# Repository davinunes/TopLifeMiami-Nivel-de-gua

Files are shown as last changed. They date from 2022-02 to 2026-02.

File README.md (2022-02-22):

# TopLifeMiami-Nivel-de-gua
Projeto para monitoramento de nível de água do Miami Beach

## Conceito

Utilizar um Sensor ultrassonico para medir o que falta de água no tanque, e calcular o que tem de água.
Então, exibir a medida atual na tela e a cada período de tempo, publicar os dados na internet.

> Esse projeto requer sinal de WiFi proximo ao microcontrolador.

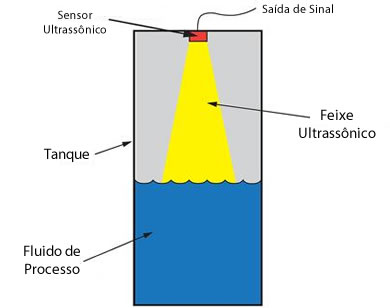
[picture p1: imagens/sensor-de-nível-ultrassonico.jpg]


Foram explorados três métodos de publicação na Internet:

- Plataforma **Adafruit.io**, um broquer MQTT popular em projetos de automação [link](https://io.adafruit.com/ilunne/dashboards/agua?kiosk=true)
- Um site particular, representando um sistema hospedado na nuvem [link](http://davinunes.eti.br/Agua/)
- API do telegram, enviando mensagens periódicas, representando um sistema de alerta

## Material RECOMENDADO

> Nota: Alguns materiais, como cano e cabo, podem ser adquiridos por metro, diminuindo o custo. Ou mesmo utilizar resto que já exista em estoque.

### Itens Essenciais

#### Sensor de Ultrassom
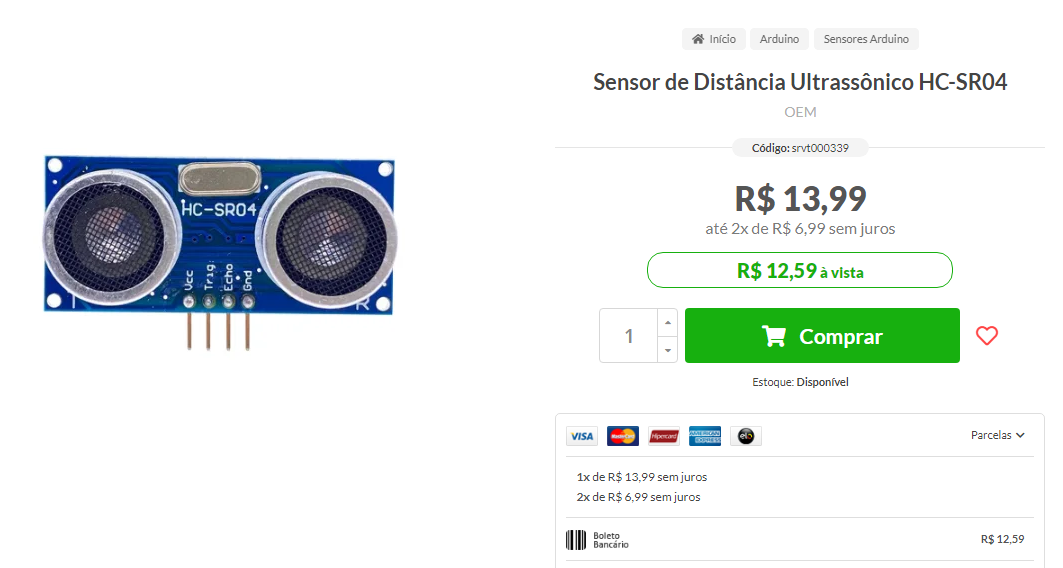
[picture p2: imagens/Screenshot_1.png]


#### Microcontrolador com WiFi
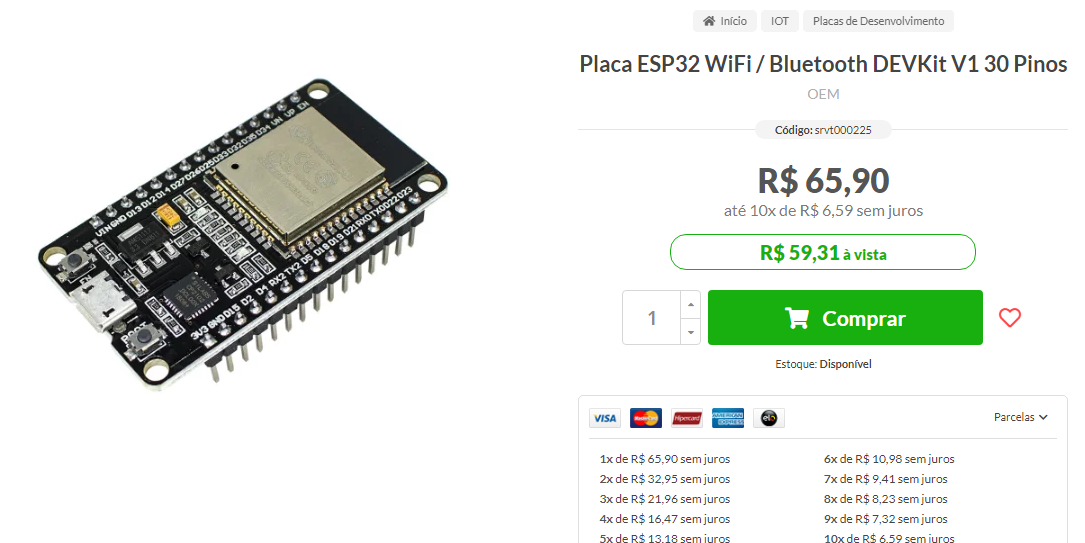
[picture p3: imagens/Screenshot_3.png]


#### Carregador de Celular com cabo microusb
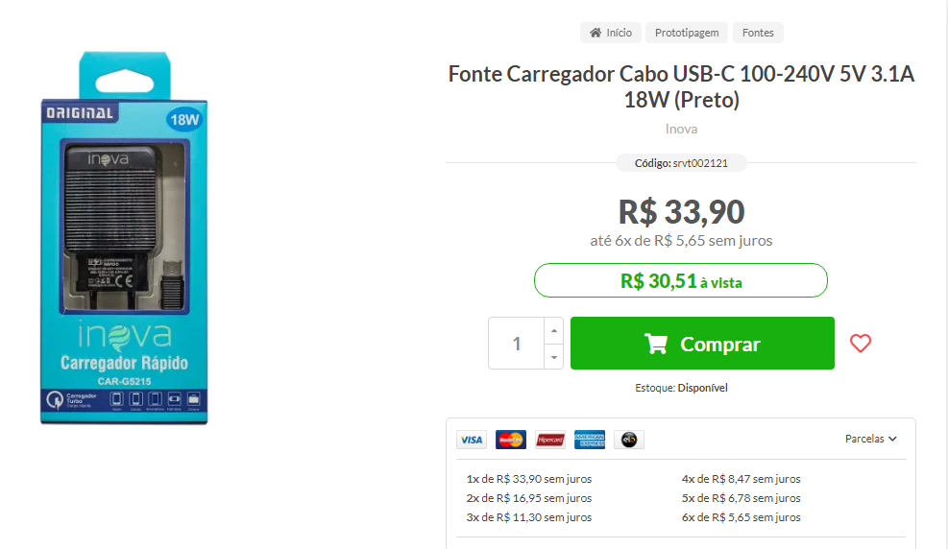
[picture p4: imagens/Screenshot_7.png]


### Itens opcionais e/ou acabamento do projeto

#### Tela de OLED
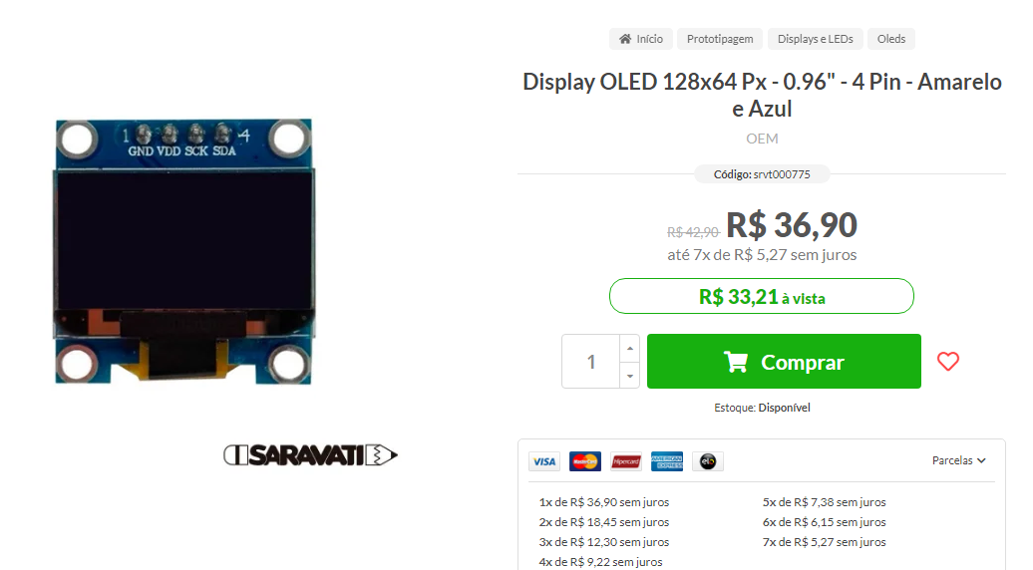
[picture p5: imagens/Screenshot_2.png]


#### Cabo para conexão com a Tela e adaptação do sensor
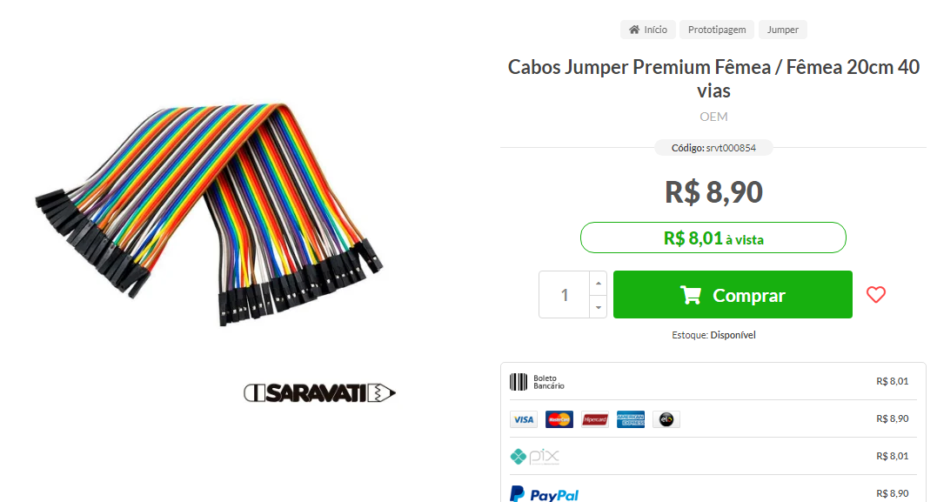
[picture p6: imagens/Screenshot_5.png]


#### Tubo para isolamento de emendas

> Ou use fita isolante

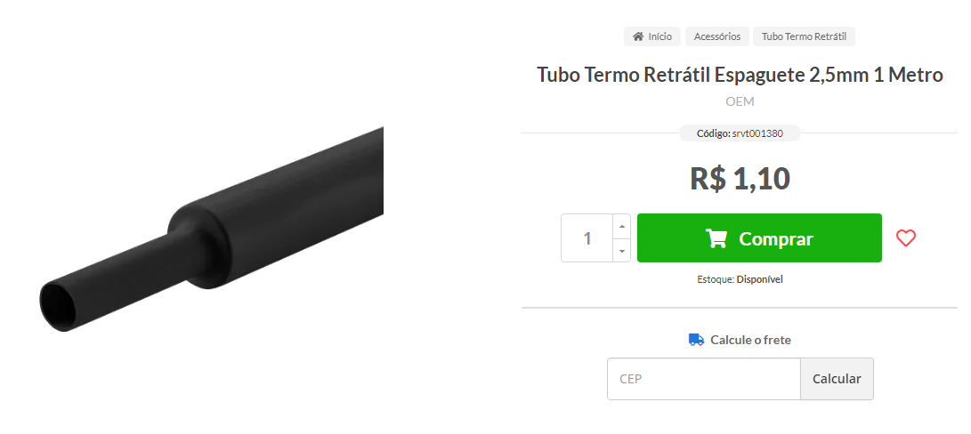
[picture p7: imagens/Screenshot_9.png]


#### Cabo para conextar o sensor da caixa ao controlador
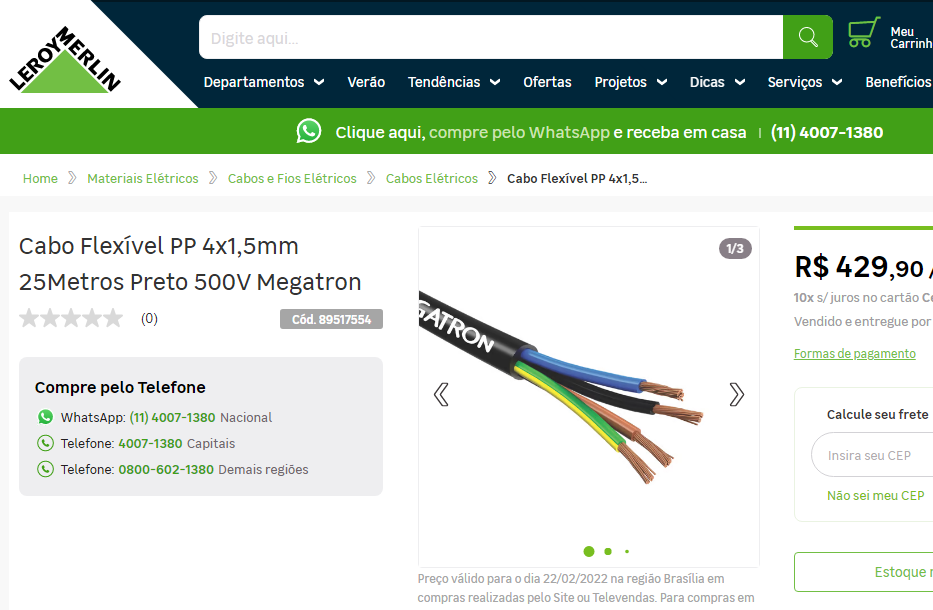
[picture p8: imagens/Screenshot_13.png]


#### Pode ser utilizado cabo de rede, em vez de cobo anterior
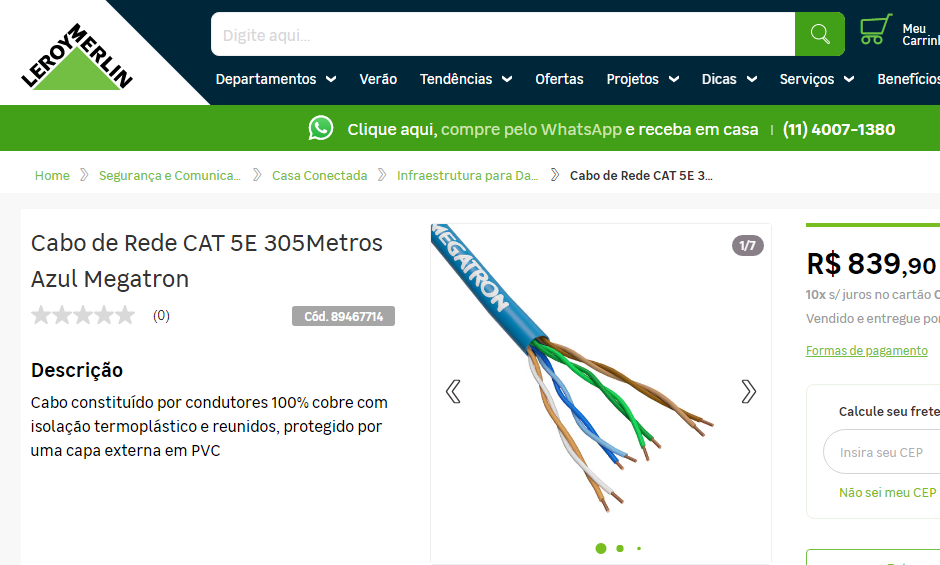
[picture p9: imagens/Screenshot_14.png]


#### CAP 50mm Esgoto, com anel de vedação
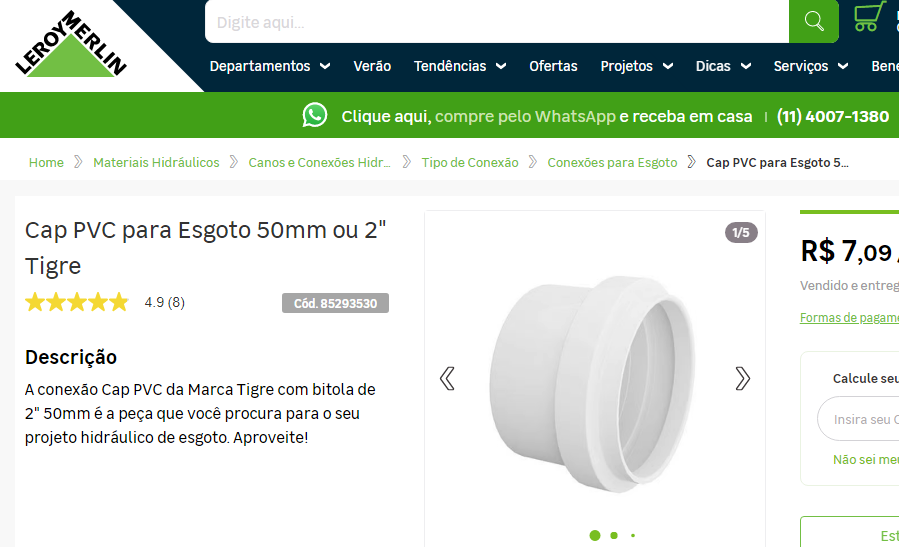
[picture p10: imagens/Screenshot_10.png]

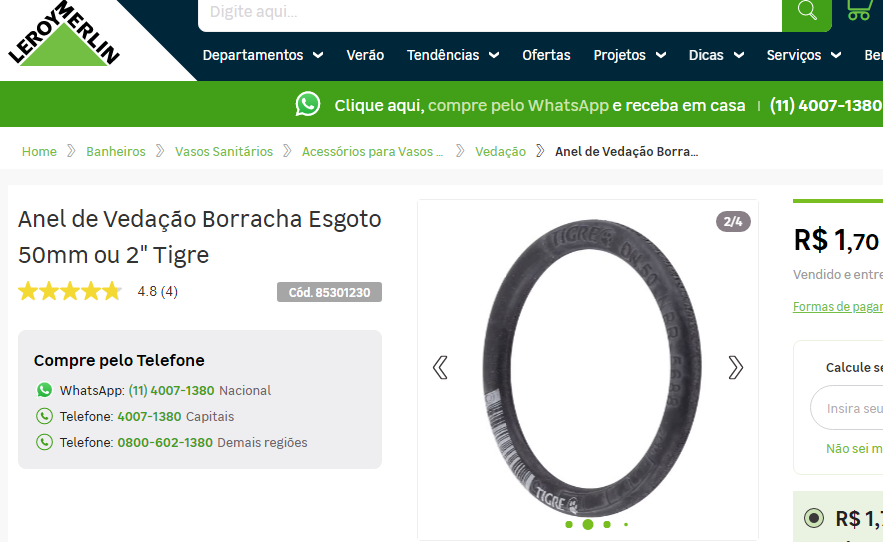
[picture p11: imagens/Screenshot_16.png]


> Nota: Se for utilizar o sensor impermeável, substituir esses dois itens e a redução de 50/25 por um cap de 25.

#### Redução 50/25mm água
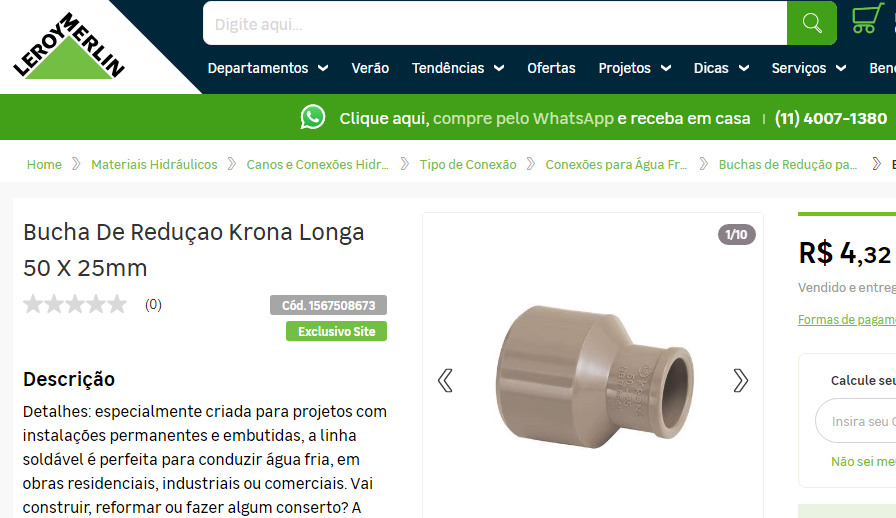
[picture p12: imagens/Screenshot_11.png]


#### Pedaço de cano de 25mm
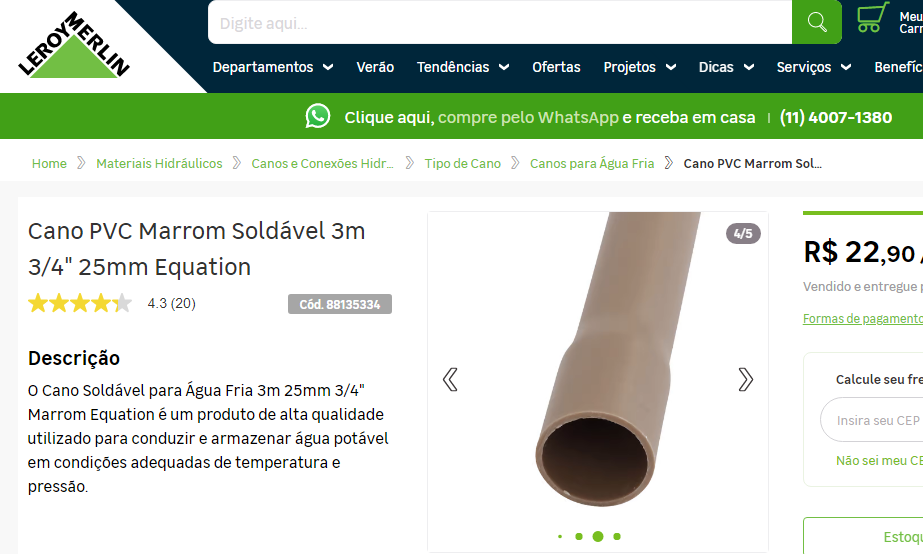
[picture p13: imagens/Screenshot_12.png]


#### Caixa de sobrepor com tampa cega
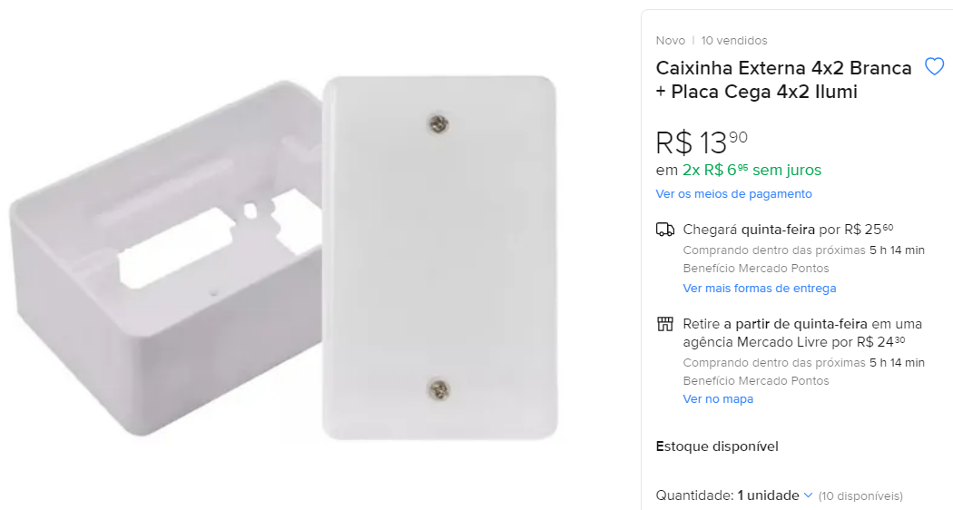
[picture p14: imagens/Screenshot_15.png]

Para instalar o LCD e acomodar o ESP32

## Execução do projeto

> O código fonte do programa está neste projeto.

- Copie o código do programa para o seu computador
- Instale a IDE Arduino, e instale as Bibliotecas Adafruit MQTT, Ultrassoinic, SSD1306
- Crie um bot no Telegram, crie um char e anote o token e o id do Chat
- Crie uma conta na Adafruit e anote o token
- Crie um site que tenha uma página que recebe dois parametros, Sendo ID do Sensor e Valor

#### A montagem das peças:

O esquema de conexão dos fios segue:
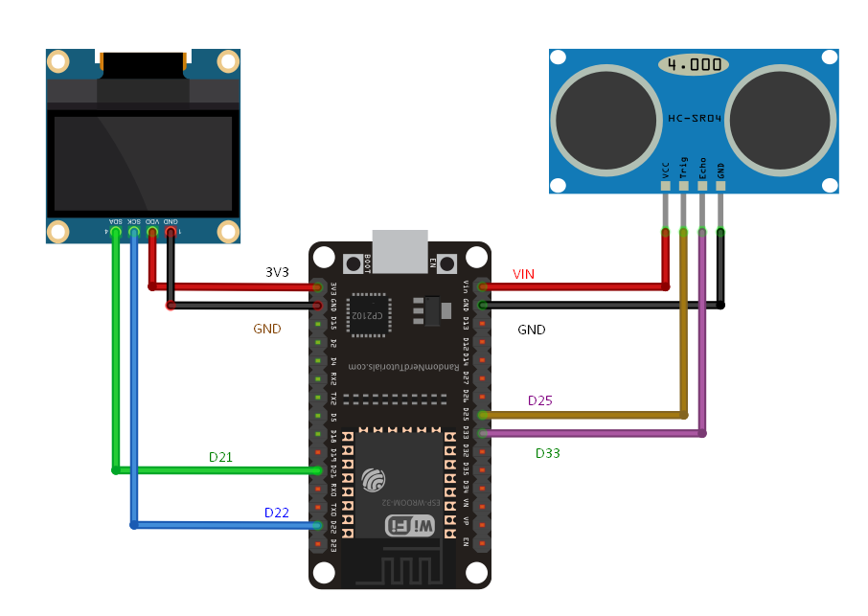
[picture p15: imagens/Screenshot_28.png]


Fure o CAP de modo que o sensor encaixe bem justo

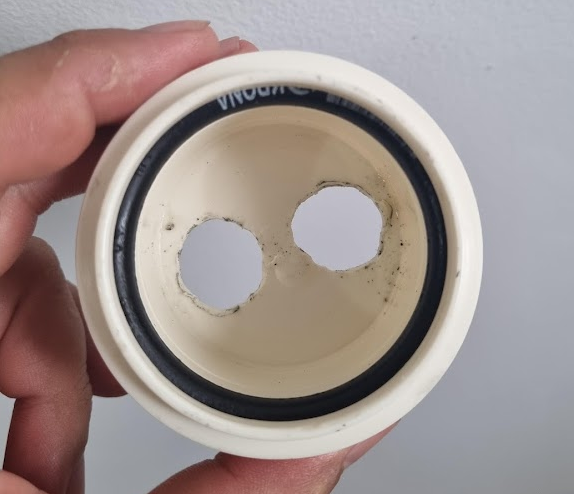
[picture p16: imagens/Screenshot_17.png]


Utilize algum material para servir de apoio ao sensor. Eu utilizei um pedaço de isopor

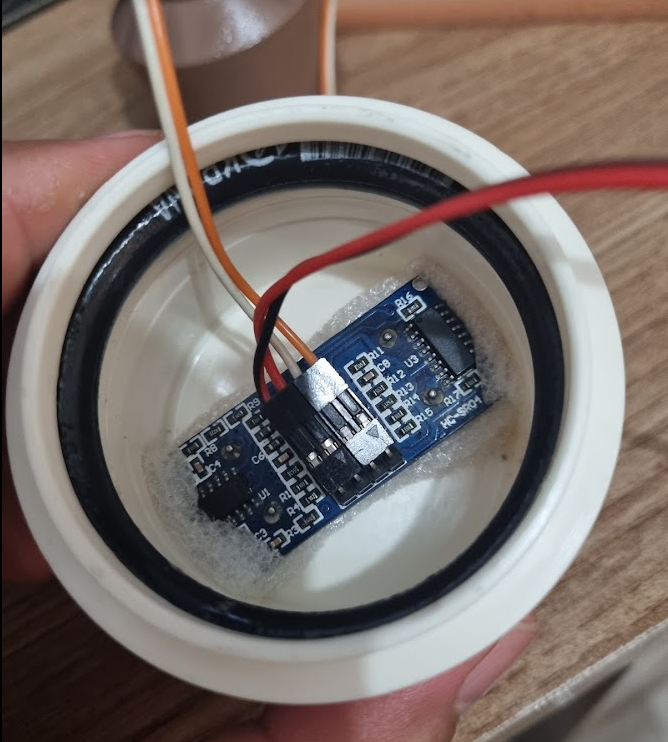
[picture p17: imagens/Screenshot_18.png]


Ajuste a altura pra sona não ficar muito pra fora

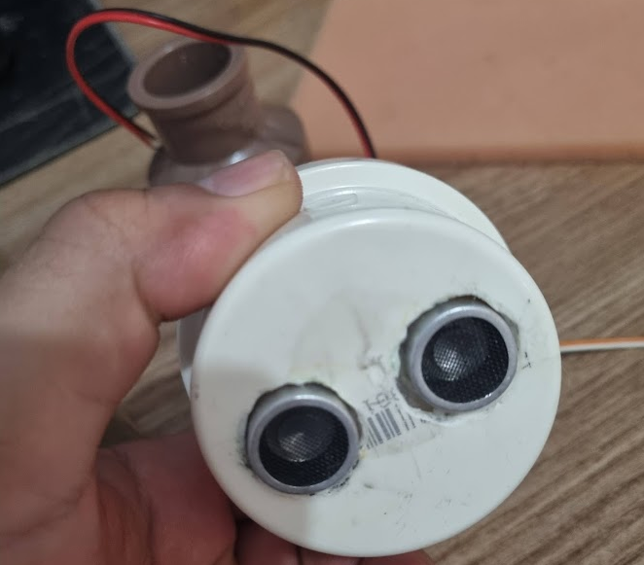
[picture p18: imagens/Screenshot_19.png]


Faça as emendas necessárias e ANOTE a sequencia correta dos fios, seguindo o codigo do projeto

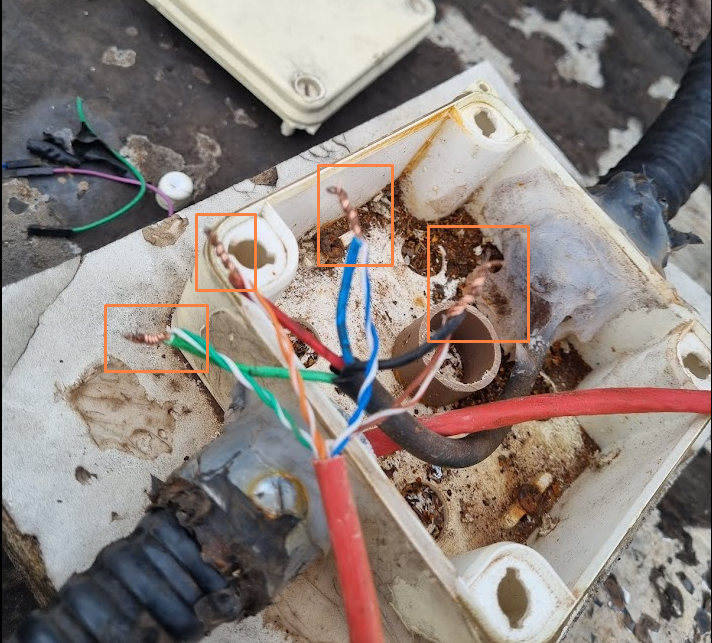
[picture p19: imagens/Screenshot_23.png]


Encaise o cap, a redução e um pedaço de cano, com o já conectado ao sensor e fixe na caixa. A Sonda não deve encostar na água

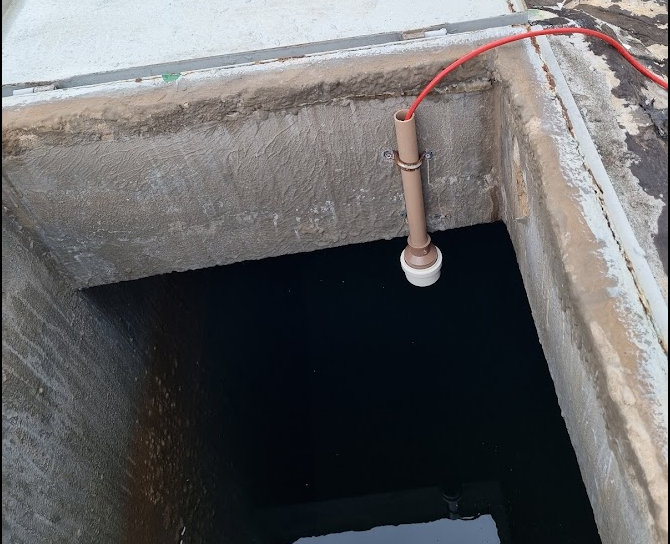
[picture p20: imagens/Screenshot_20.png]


Com uma trena, meça quantos centimetros tem entre a sonda e o nivel maximo da água. Essa informação deve ser inserida no programa antes de gravar

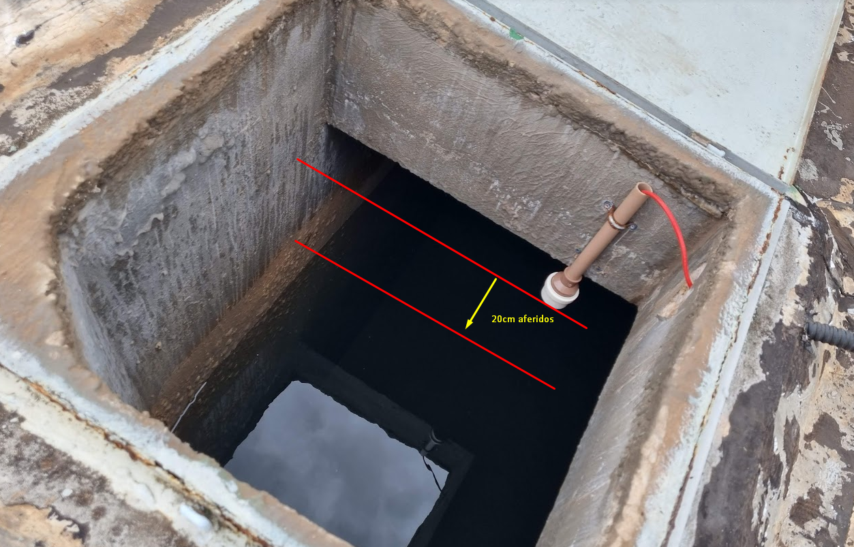
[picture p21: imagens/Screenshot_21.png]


Faça os acabamentos necessários. Esta etapa pode variar de caso a caso

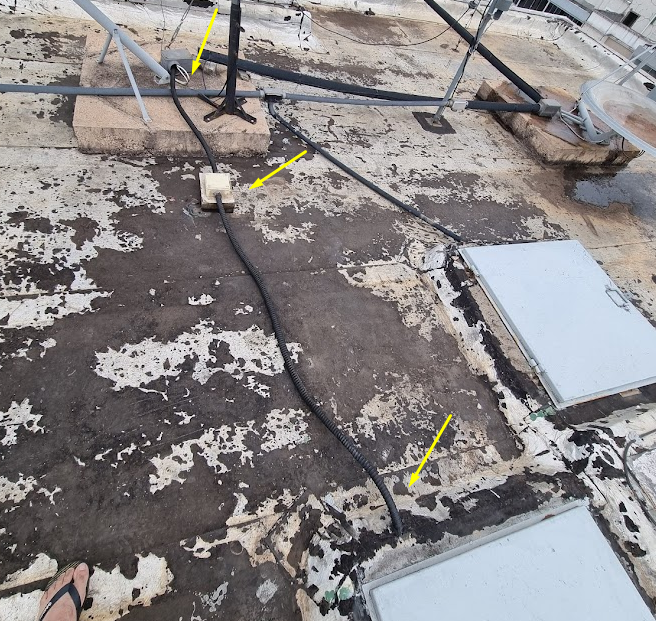
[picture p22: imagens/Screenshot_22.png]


Na casa de máquinas, ou onde for ficar o microcontrolador, faça as conexões conforme o projeto

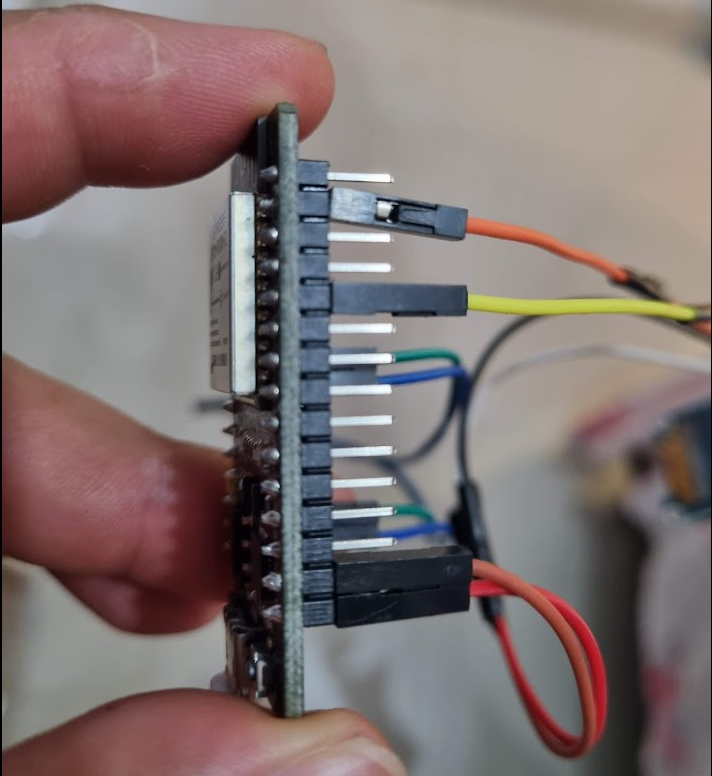
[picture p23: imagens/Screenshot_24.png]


Imagem do armário na casa de máquinas

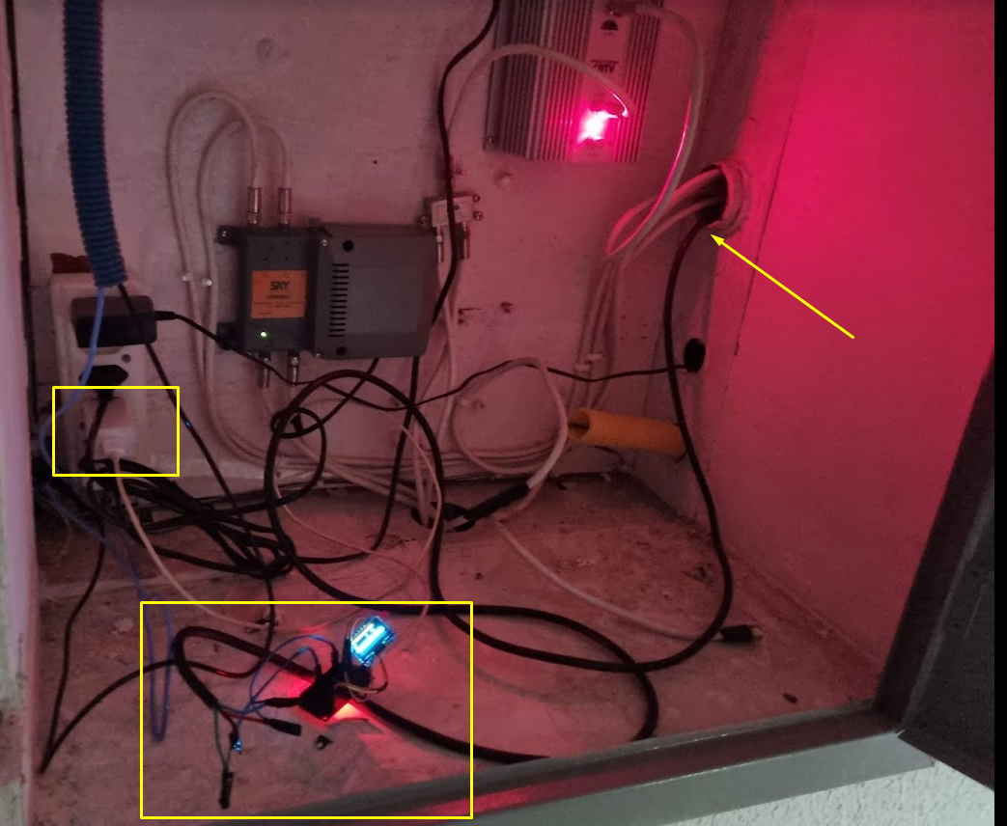
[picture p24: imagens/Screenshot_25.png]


> É verdade, ficou bem feio mas vamos logo mais acomodar em uma caixa de sobrepor e prender a tela na tampa cega.

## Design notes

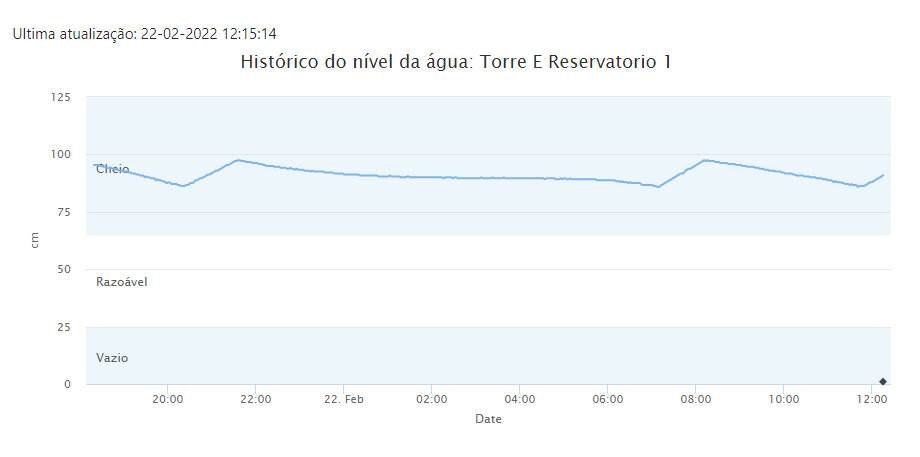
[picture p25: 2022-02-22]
imagens/Screenshot_26.png

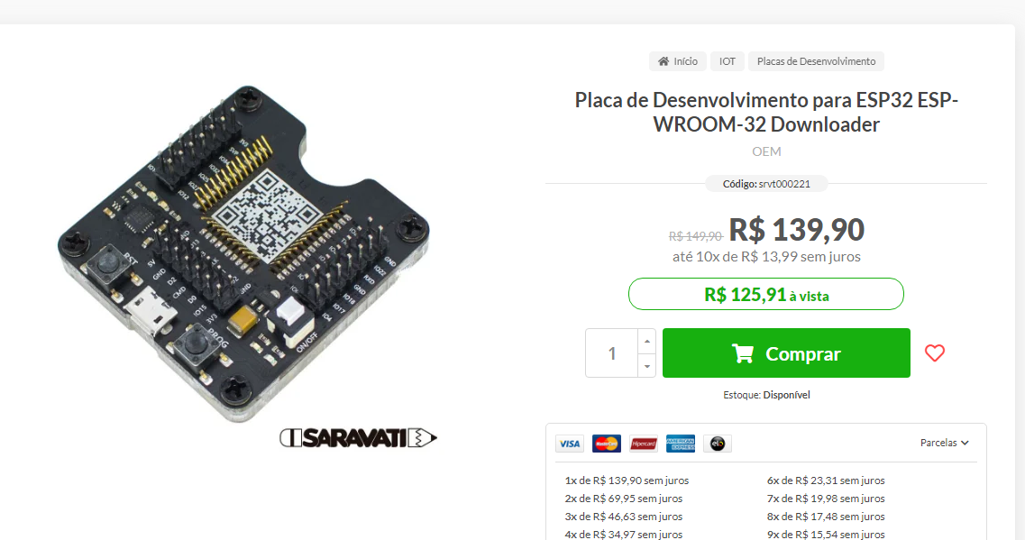
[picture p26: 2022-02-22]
imagens/Screenshot_6.png

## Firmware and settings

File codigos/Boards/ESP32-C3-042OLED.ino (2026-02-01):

/*
  SKETCH PORTADO PARA ESP32-C3 COM DISPLAY OLED 0.42"
  - Biblioteca de display alterada para U8g2.
  - Mantém todas as funcionalidades originais.

  Bibliotecas necessárias (instalar via Gerenciador de Bibliotecas do Arduino IDE):
  - "U8g2" by oliver
  - "Ultrasonic" by Erick Simões
  - "ArduinoJson" by Benoit Blanchon
*/

// ==================== BIBLIOTECAS ====================
#include <WiFi.h>
#include "esp_wifi.h"
#include <HTTPClient.h>
#include <WebServer.h>
#include <Preferences.h>
#include <WiFiClientSecure.h>
#include <U8g2lib.h>
#include <Ultrasonic.h>
#include <Wire.h>
#include <DNSServer.h>
#include <ArduinoJson.h>
#include <time.h>
#include <Update.h>
#include "mbedtls/base64.h"
#include <freertos/FreeRTOS.h>
#include <freertos/task.h>
#include <freertos/semphr.h>

// ==================== CONFIGURAÇÕES DA PLACA E FIRMWARE ====================
#define BOARD_MODEL "ESP32-C3-OLED-042"
#define FW_VERSION 3.0

// ==================== CONFIGURAÇÕES DE PINOS (ESP32-C3) ====================
#define LED_PIN 8
#define TRIGGER_PIN 20  // GPIO20 como trigger
#define ECHO_PIN 21     // GPIO21 como echo
#define I2C_SDA_PIN 5
#define I2C_SCL_PIN 6

// ==================== CONFIGURAÇÕES U8G2 ====================
// Construtor para o display SSD1306 de 72x40 pixels em modo I2C de hardware.
// U8G2_R0 = Sem rotação. Se a tela ficar de cabeça para baixo, troque para U8G2_R2.
U8G2_SSD1306_72X40_ER_F_HW_I2C u8g2(U8G2_R0, /* reset=*/ U8X8_PIN_NONE);


// ==================== CONFIGURAÇÕES GERAIS ====================
#define AP_MODE_DURATION 120000

const char* ntpServer = "pool.ntp.org";
const long  gmtOffset_sec = -3 * 3600;
const int   daylightOffset_sec = 0;

int idSensor = 3;
int distanciaSonda = 0;
int alturaAgua = 200;
String nomeDaSonda = "Torre A Reservatório 01";
String novoUrlSite = "https://app.digitalinovation.com.br";
String urlVersao = "https://app.digitalinovation.com.br/version.json";
String remoteConfigUrl = "https://app.digitalinovation.com.br/remote.json";
String pingBaseUrl = "https://app.digitalinovation.com.br/ping/";
int alertLevelCm = 50;
String deviceUuid = "";

// ==================== VARIÁVEIS GLOBAIS ====================
// ==================== CLASSE DE LOG (CIRCULAR BUFFER) ====================
#define LOG_SIZE 2048
class DebugLog {
  private:
    char buffer[LOG_SIZE];
    int head;
    bool wrapped;
    SemaphoreHandle_t mutex;
  
  public:
    DebugLog() : head(0), wrapped(false) {
        mutex = xSemaphoreCreateMutex();
        memset(buffer, 0, LOG_SIZE);
    }

    void log(String msg) {
        if (mutex != NULL) xSemaphoreTake(mutex, portMAX_DELAY);
        
        String timeStr = "[" + String(millis()) + "] ";
        String fullMsg = timeStr + msg + "\n";
        
        // Serial output imediato
        Serial.print(fullMsg);
        
        // Circular Buffer
        for(int i=0; i < fullMsg.length(); i++) {
            buffer[head] = fullMsg[i];
            head++;
            if(head >= LOG_SIZE) {
                head = 0;
                wrapped = true;
            }
        }
        
        if (mutex != NULL) xSemaphoreGive(mutex);
    }
    
    String getLogString() {
        if (mutex != NULL) xSemaphoreTake(mutex, portMAX_DELAY);
        String s = "";
        s.reserve(LOG_SIZE);
        
        if (wrapped) {
            for(int i=head; i < LOG_SIZE; i++) s += buffer[i];
            for(int i=0; i < head; i++) s += buffer[i];
        } else {
            for(int i=0; i < head; i++) s += buffer[i];
        }
        
        if (mutex != NULL) xSemaphoreGive(mutex);
        return s;
    }
    
    void clear() {
        if (mutex != NULL) xSemaphoreTake(mutex, portMAX_DELAY);
        head = 0;
        wrapped = false;
        memset(buffer, 0, LOG_SIZE);
        if (mutex != NULL) xSemaphoreGive(mutex);
    }

    String toHtml() {
      if (mutex != NULL) xSemaphoreTake(mutex, portMAX_DELAY);
      String html = "<!DOCTYPE html><html><head><meta charset='UTF-8'><meta http-equiv='refresh' content='5'>";
      html += "<style>body{background:#1e1e1e;color:#d4d4d4;font-family:monospace;padding:20px;}";
      html += ".log{white-space:pre-wrap;word-wrap:break-word;} .time{color:#569cd6;} .err{color:#f44747;}</style></head><body>";
      html += "<h2>Debug Log (Auto Refresh 5s)</h2><form action='/debug/clear' method='POST'><button>Limpar Log</button></form><hr><div class='log'>";
      
      String content = "";
      content.reserve(LOG_SIZE);
      if (wrapped) {
          for(int i=head; i < LOG_SIZE; i++) content += buffer[i];
          for(int i=0; i < head; i++) content += buffer[i];
      } else {
          for(int i=0; i < head; i++) content += buffer[i];
      }
      
      // Escape basico e formatacao
      content.replace("<", "&lt;");
      content.replace(">", "&gt;");
      content.replace("\n", "<br>");
      
      html += content;
      html += "</div></body></html>";
      
      if (mutex != NULL) xSemaphoreGive(mutex);
      return html;
    }
};

DebugLog debugLog;

// ==================== VARIÁVEIS GLOBAIS ====================
Ultrasonic sonar1(TRIGGER_PIN, ECHO_PIN, 40000UL); // Timeout aumentado
int distance = 0;

// Urls atualizadas (REMOVED DUPLICATE)

// Mutexes para Thread Safety
SemaphoreHandle_t logMutex;
SemaphoreHandle_t configMutex;
SemaphoreHandle_t sensorMutex;
TaskHandle_t iotTaskHandle;

// Historico para moda
#define HISTORY_SIZE 120
int history[HISTORY_SIZE];
int historyCount = 0;
int historyIndex = 0;

WebServer server(80);
DNSServer dnsServer;
Preferences prefs;
String StatusInternet = "Sem Wifi...";

unsigned long lastDisplayUpdate = 0;
const unsigned long displayInterval = 500;
unsigned long lastTime = 0;
unsigned long timerDelay = 15000;
unsigned long bootTime = 0;
bool inAPMode = false;

unsigned long lastLedToggle = 0;
bool ledState = false;
unsigned long ledInterval = 1000;

struct Config {
  String ssid;
  String pass;
  String sensorId;
  String nomeSonda;
};

// ==================== PROTÓTIPOS DE FUNÇÕES ====================
void switchToAPMode();
void switchToStationMode();
void updateLed();
void handleWiFiEvent(WiFiEvent_t event);
void sonar();
void tela();
void IoT();
Config loadConfig();
void saveConfig(String ssid, String pass, String sensorId, String nomeSonda);
void startAccessPoint();
void setupWebServer();
void handleRoot();
void handleSave();
void performUpdate(String url);
void getRemoteConfig();
void sendPing();
void publishSensorReading(int sensorValue);
void handleEsquema();
void handleWiFiScan();
void handleNotFound();
String urlEncode(const String& str);
void setupDeviceID();
void syncTime();
String escapeHTML(String input);

// Forward Declarations
void initRemoteParams();
void saveRemoteParams();
void handleDebug();
void handleDebugClear();

// ==================== SETUP ====================
// ==================== SETUP ====================
void setup() {
  Serial.begin(115200);
  
  // Inicializa Mutexes
  logMutex = xSemaphoreCreateMutex();
  configMutex = xSemaphoreCreateMutex();
  sensorMutex = xSemaphoreCreateMutex();

  pinMode(LED_PIN, OUTPUT);
  digitalWrite(LED_PIN, LOW);

  WiFi.mode(WIFI_STA);
  // WiFi.enableIPv6();  // Descomentar se necessario e suportado pela versao do core C3
  
  setupDeviceID();

  // Inicializa o I2C e o display com U8g2
  Wire.begin(I2C_SDA_PIN, I2C_SCL_PIN);
  u8g2.begin();

  // Mensagem inicial com U8g2
  u8g2.clearBuffer();
  u8g2.setFont(u8g2_font_6x10_tf); // Seleciona uma fonte pequena
  u8g2.drawStr(0, 10, "Iniciando...");
  u8g2.sendBuffer(); // Envia para a tela
  delay(1000);

  Config cfg = loadConfig();
  idSensor = cfg.sensorId.toInt();
  nomeDaSonda = cfg.nomeSonda;

  WiFi.onEvent(handleWiFiEvent);

  bootTime = millis();
  
  // Inicializa em modo AP para configuracao
  switchToAPMode();
  
  initRemoteParams(); // Carrega parametros salvos
  setupWebServer();
  debugLog.log("Setup completo. Iniciando Tasks...");

  // Inicializa Task IoT no Core 0 (Unico no C3)
  xTaskCreatePinnedToCore(
      IoT_Task,       // Funcao da tarefa
      "IoT_Task",     // Nome
      16384,          // Stack Size (16KB)
      NULL,           // Params
      1,              // Prioridade
      &iotTaskHandle, // Handle
      0               // Core ID (0)
  );
}

// ==================== LOOP PRINCIPAL ====================
// ==================== LOOP PRINCIPAL ====================
void loop() {
  // Leitura do Sonar (Agora seguro por mutex)
  if (!inAPMode) {
    sonar();
  }

  // Atualizacao do Display (Mantendo logica original)
  if (millis() - lastDisplayUpdate >= displayInterval) {
    tela();
    lastDisplayUpdate = millis();
  }

  // Timeout do modo AP
  if (inAPMode && (millis() - bootTime > AP_MODE_DURATION)) {
    switchToStationMode();
  }

  updateLed();
  server.handleClient(); // WebServer roda no Loop principal

  if (inAPMode) {
    dnsServer.processNextRequest();
  }
  
  // Yield para dar chance ao WiFi Stack (Crucial no Single Core)
  delay(2); 
}

// ==================== FUNÇÃO DE TELA (com U8g2) ====================
void tela() {
  u8g2.clearBuffer();
  u8g2.setFont(u8g2_font_6x10_tf);

  if (inAPMode) {
    // --- TELA PARA MODO ACCESS POINT (SETUP) ---
    // Linha 1: Tempo restante para modo estação
    unsigned long timeElapsed = millis() - bootTime;
    long timeLeftMs = AP_MODE_DURATION - timeElapsed;
    if (timeLeftMs < 0) timeLeftMs = 0;
    int minutes = (timeLeftMs / 1000) / 60;
    int seconds = (timeLeftMs / 1000) % 60;
    char timeStr[20];
    sprintf(timeStr, "Tempo: %02d:%02d", minutes, seconds);
    u8g2.drawStr(0, 10, timeStr);

    // Linha 2: Nome da rede AP
    u8g2.drawStr(0, 22, WiFi.softAPSSID().c_str());

    // Linha 3: IP do AP
    u8g2.drawStr(0, 34, WiFi.softAPIP().toString().c_str());

  } else {
    // --- TELA PARA MODO ESTAÇÃO (NORMAL) ---
    // Linha 1: Nível da água
    char buffer[20];
    sprintf(buffer, "Nivel: %dcm", distance);
    u8g2.drawStr(0, 10, buffer);

    // Linha 2: Status do WiFi
    const char* wifiStatus = (WiFi.status() == WL_CONNECTED) ? "WiFi: UP" : "WiFi: DOWN";
    u8g2.drawStr(0, 22, wifiStatus);

    // Linha 3: IP ou mensagem de conexão
    if (WiFi.status() == WL_CONNECTED) {
      u8g2.drawStr(0, 34, WiFi.localIP().toString().c_str());
    } else {
      u8g2.drawStr(0, 34, "Conectando...");
    }
  }
  u8g2.sendBuffer();
}


// ==================== FUNÇÕES DE IOT E REDE (sem alterações na lógica) ====================

// ==================== HELPER FUNCTIONS ====================
// Calcula a moda das ultimas leituras para estabilidade
int calculateMode() {
    if (historyCount == 0) return 0;
    
    // Copia para ordenar
    int sorted[HISTORY_SIZE];
    int count = historyCount;
    
    // Acesso thread-safe ao historico
    if (xSemaphoreTake(sensorMutex, portMAX_DELAY)) {
         for(int i=0; i<count; i++) sorted[i] = history[i];
         xSemaphoreGive(sensorMutex);
    }
    
    // Bubble sort simples (array pequeno)
    for(int i=0; i<count-1; i++) {
        for(int j=0; j<count-i-1; j++) {
            if(sorted[j] > sorted[j+1]) {
                int temp = sorted[j];
                sorted[j] = sorted[j+1];
                sorted[j+1] = temp;
            }
        }
    }
    
    int mode = sorted[0];
    int maxCount = 1;
    int currentCount = 1;
    
    for(int i=1; i<count; i++) {
        if (sorted[i] == sorted[i-1]) {
            currentCount++;
        } else {
            if (currentCount > maxCount) {
                maxCount = currentCount;
                mode = sorted[i-1];
            }
            currentCount = 1;
        }
    }
    if (currentCount > maxCount) {
        mode = sorted[count-1];
    }
    
    return mode;
}

// Helper Base64 simplificado usando mbedtls
String base64Encode(String input) {
  size_t outputLength = 0;
  unsigned char *outputBuffer = new unsigned char[input.length() * 2]; // Aloca com sobra
  
  int ret = mbedtls_base64_encode(outputBuffer, input.length() * 2, &outputLength, (const unsigned char*)input.c_str(), input.length());
  
  String encoded = "";
  if (ret == 0) {
      outputBuffer[outputLength] = '\0'; 
      encoded = String((char*)outputBuffer);
  } else {
      encoded = "encode_error";
  }
  
  delete[] outputBuffer;
  return encoded;
}

// ==================== HELPER DE REDE (DEEP DEBUG) ====================
int performHttpGet(String url, String &payload) {
    if (WiFi.status() != WL_CONNECTED) {
        debugLog.log("Abort Http: Sem WiFi");
        return -1;
    }

    // === DEEP DEBUGGING START ===
    unsigned long startTotal = millis();
    String host = "";
    // Extrai o host para debug de DNS
    int slashIndex = url.indexOf("//");
    if (slashIndex != -1) {
        int nextSlash = url.indexOf("/", slashIndex + 2);
        if (nextSlash != -1) host = url.substring(slashIndex + 2, nextSlash);
        else host = url.substring(slashIndex + 2);
    }
    
    // Debug DNS
    if(host.length() > 0) {
        IPAddress resolvedIP;
        unsigned long startDNS = millis();
        bool dnsFound = WiFi.hostByName(host.c_str(), resolvedIP);
        long dnsTime = millis() - startDNS;
        if(dnsFound) {
            debugLog.log("DNS: " + host + " -> " + resolvedIP.toString() + " (" + String(dnsTime) + "ms)");
        } else {
            debugLog.log("DNS FAIL: " + host + " (" + String(dnsTime) + "ms)");
            return -1; // Falha DNS aborta cedo
        }
    }
    
    debugLog.log("Req: " + url);
    debugLog.log("Heap: " + String(ESP.getFreeHeap()));

    HTTPClient http;
    int httpCode = -1;
    
    if (url.startsWith("https")) {
        WiFiClientSecure client;
        client.setInsecure();
        client.setHandshakeTimeout(30000); // 30s handshake timeout
        
        http.begin(client, url);
        http.setTimeout(30000); 
        http.setFollowRedirects(HTTPC_STRICT_FOLLOW_REDIRECTS);
        httpCode = http.GET();
        
        if (httpCode > 0 && httpCode == HTTP_CODE_OK) {
             payload = http.getString();
        }
    } else {
        WiFiClient client;
        http.begin(client, url);
        http.setTimeout(30000); 
        http.setFollowRedirects(HTTPC_STRICT_FOLLOW_REDIRECTS);
        httpCode = http.GET();
        
        if (httpCode > 0 && httpCode == HTTP_CODE_OK) {
             payload = http.getString();
        }
    }
    
    // Debug Connection + Request
    if (httpCode > 0) {
        if (httpCode == HTTP_CODE_OK) {
             int pLen = payload.length();
             debugLog.log("Payload bytes: " + String(pLen));
             if (pLen > 0) {
                 String preview = payload.substring(0, (pLen > 100 ? 100 : pLen));
                 preview.replace("\n", " ");
                 preview.replace("\r", "");
                 debugLog.log("Data: " + preview + "...");
             }
        }
    } else {
         debugLog.log("Erro Req: " + http.errorToString(httpCode));
    }
    
    http.end();
    debugLog.log("Total Time: " + String(millis() - startTotal) + "ms");
    debugLog.log("---------------------------");
    
    return httpCode;
}

void IoT_Task(void *parameter) {
    debugLog.log("Tarefa IoT iniciada no Core " + String(xPortGetCoreID()));
    
    // Tentativa inicial de conexao
    if (!inAPMode) {
        Config cfg = loadConfig();
        if (cfg.ssid != "" && cfg.ssid != "Wokwi") {
             debugLog.log("Tentando conectar a: " + cfg.ssid);
             WiFi.begin(cfg.ssid.c_str(), cfg.pass.c_str());
        } else {
             debugLog.log("SSID nao configurado. Iniciando AP.");
             switchToAPMode();
        }
    }

    // Variaveis locais para controle de tentativas
    static int connectionAttempts = 0;
    const int maxAttempts = 10;

    for(;;) {
        // Verifica conexao
        if (WiFi.status() == WL_CONNECTED) {
            // Reset contador se conectado
            connectionAttempts = 0;

            // Log de IP para debug
            static bool ipLogged = false;
            if (!ipLogged) {
                 debugLog.log("WiFi OK. IPv4: " + WiFi.localIP().toString());
                 ipLogged = true;
            }

            // OBTEM A MODA DAS ULTIMAS LEITURAS
            int stableValue = calculateMode();
            
            // Envia dados para o servidor
            publishSensorReading(stableValue);
            
            // Verifica por atualizacoes de firmware e configuracoes
            getRemoteConfig();

            // Envia ping para monitoramento
            sendPing();
            
        } else {
             // Se nao estiver em modo AP, tenta gerenciar a conexao
             if (!inAPMode) {
                 connectionAttempts++;
                 debugLog.log("IoT: Sem WiFi (" + String(connectionAttempts) + "/" + String(maxAttempts) + ")");
                 
                 // Na primeira tentativa da sequencia, carrega as credenciais e inicia a conexao
                 if (connectionAttempts == 1) {
                      Config cfg = loadConfig();
                      if (cfg.ssid != "" && cfg.ssid != "Wokwi") {
                          debugLog.log("Iniciando conexao com: " + cfg.ssid);
                          WiFi.begin(cfg.ssid.c_str(), cfg.pass.c_str());
                      } else {
                          debugLog.log("SSID nao configurado. Mudando para AP.");
                          switchToAPMode();
                          connectionAttempts = 0;
                      }
                 }
                 else if (connectionAttempts >= maxAttempts) {
                      debugLog.log("Falha na conexao. Mudando para AP.");
                      switchToAPMode();
                      connectionAttempts = 0;
                 } 
             }
        }
        
        // Aguarda o intervalo (bloqueando apenas esta tarefa)
        unsigned long delayTime = timerDelay > 10000 ? timerDelay : 60000;
        
        // Se estiver desconectado mas tentando, aguarda menos tempo para retentar
        if (!inAPMode && WiFi.status() != WL_CONNECTED) {
            delayTime = 5000; // Tenta a cada 5 segundos
        }
        
        vTaskDelay(pdMS_TO_TICKS(delayTime)); 
    }
}

void performUpdate(String url) {
    // Atualiza tela com U8g2
    u8g2.clearBuffer();
    u8g2.setFont(u8g2_font_6x10_tf);
    u8g2.drawStr(0, 10, "Atualizando...");
    u8g2.drawStr(0, 22, "Baixando FW...");
    u8g2.sendBuffer();

    // Configura Client (Secure ou Insecure) usando HEAP
    HTTPClient http;
    WiFiClientSecure *clientSecure = nullptr;
    WiFiClient *clientInsecure = nullptr;
    
    // Logica de HTTPS
    if (url.startsWith("https")) {
        clientSecure = new WiFiClientSecure();
        clientSecure->setInsecure();
        clientSecure->setHandshakeTimeout(30000); 
        http.begin(*clientSecure, url);
    } else {
        clientInsecure = new WiFiClient();
        http.begin(*clientInsecure, url);
    }
    
    http.setTimeout(30000);
    http.setFollowRedirects(HTTPC_STRICT_FOLLOW_REDIRECTS);
    
    int httpCode = http.GET();
    // Redirect manual removido pois setFollowRedirects resolve

    if (httpCode != HTTP_CODE_OK) {
        Serial.printf("Erro no download, codigo: %d\n", httpCode);
        u8g2.clearBuffer();
        u8g2.drawStr(0, 10, "Falha no FW!");
        String codeStr = "Cod: " + String(httpCode);
        u8g2.drawStr(0, 22, codeStr.c_str());
        u8g2.sendBuffer();
        
        http.end();
        if (clientSecure) delete clientSecure;
        if (clientInsecure) delete clientInsecure;
        return;
    }

    int contentLength = http.getSize();
    if (contentLength <= 0) {
        Serial.println("Tamanho do conteudo invalido.");
        http.end();
        if (clientSecure) delete clientSecure;
        if (clientInsecure) delete clientInsecure;
        return;
    }

    if (!Update.begin(contentLength)) {
        Serial.println("Nao ha espaco para atualizar.");
        http.end();
        if (clientSecure) delete clientSecure;
        if (clientInsecure) delete clientInsecure;
        return;
    }

    u8g2.clearBuffer();
    u8g2.drawStr(0, 10, "Gravando...");
    u8g2.drawStr(0, 22, "Nao desligue!");
    u8g2.sendBuffer();

    size_t written = Update.writeStream(http.getStream());

    if (written != contentLength) {
          Serial.printf("Escrita falhou! Escrito %d de %d bytes\n", written, contentLength);
    } else {
          if (Update.end()) {
              Serial.println("Atualizacao finalizada com sucesso!");
              u8g2.clearBuffer();
              u8g2.drawStr(0, 10, "Sucesso!");
              u8g2.drawStr(0, 22, "Reiniciando...");
              u8g2.sendBuffer();
              delay(2000);
              
              http.end();
              if (clientSecure) delete clientSecure;
              if (clientInsecure) delete clientInsecure;
              
              ESP.restart();
          } else {
              Serial.println("Erro ao finalizar a atualizacao: " + String(Update.getError()));
          }
    }
    
    http.end();
    if (clientSecure) delete clientSecure;
    if (clientInsecure) delete clientInsecure;
}


// =========================================================================
// AS FUNÇÕES ABAIXO NÃO FORAM ALTERADAS, APENAS REPRODUZIDAS INTEGRALMENTE
// =========================================================================


// ==================== FUNÇÕES DE REDE ====================
void switchToAPMode() {
  WiFi.disconnect(true);
  WiFi.mode(WIFI_AP);
  startAccessPoint();
  StatusInternet = "Modo AP";
  inAPMode = true;
  ledInterval = 100;
  digitalWrite(LED_PIN, HIGH);
  Serial.println("Modo AP ativado");
}

void switchToStationMode() {
  Config cfg = loadConfig();
  WiFi.disconnect(true);
  WiFi.mode(WIFI_STA);
  WiFi.begin(cfg.ssid.c_str(), cfg.pass.c_str());
  inAPMode = false;
  ledInterval = 1000;
  Serial.println("Tentando conectar como estação...");
}
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

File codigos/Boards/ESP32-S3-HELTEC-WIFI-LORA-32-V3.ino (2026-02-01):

/*
  SKETCH ADAPTADO PARA A PLACA HELTEC WIFI LORA 32 (V3)
  - Modelo da Placa: ESP32-S3-HELTEC-WIFI-LORA-32-V3
  - Versão: 1.0
  - Display OLED integrado: SDA(17), SCL(18), RST(21), Vext Power(2)
  - Sensor Sonar: TRIGGER(33), ECHO(34)
  - Pinout: https://resource.heltec.cn/download/WiFi_LoRa_32_V3/HTIT-WB32LA_V3(Rev1.1).pdf
  - Pinout: https://www.espboards.dev/img/qS1QpyeC_N-1000.png
  - Dataseet: https://www.espressif.com/sites/default/files/documentation/esp32-s3_datasheet_en.pdf
*/

#include <WiFi.h>
#include "esp_wifi.h"
#include <HTTPClient.h>
#include "mbedtls/base64.h" // Importante para codificar logs
#include <WebServer.h>
#include <Preferences.h>
#include "SSD1306Wire.h"
#include <Ultrasonic.h>
#include <DNSServer.h>
#include <WiFiClientSecure.h>
#include <Update.h>
#include <ArduinoJson.h>
#include <time.h>

// ==================== GLOBAL RESOURCES ====================
// Mutexes
SemaphoreHandle_t logMutex;
SemaphoreHandle_t configMutex;
SemaphoreHandle_t sensorMutex;
TaskHandle_t iotTaskHandle;

// ==================== DEBUGGING ====================
class DebugLog {
  private:
    static const int MAX_LOGS = 50;
    String logs[MAX_LOGS];
    int head = 0;
    int count = 0;

  public:
    void log(String msg, bool timestamp = true) {
      if (xSemaphoreTake(logMutex, portMAX_DELAY)) {
          if (timestamp) {
            unsigned long m = millis();
            String st = "[" + String(m) + "] ";
            msg = st + msg;
          }
          
          logs[head] = msg;
          head = (head + 1) % MAX_LOGS;
          if (count < MAX_LOGS) {
            count++;
          }
          Serial.println(msg);
          xSemaphoreGive(logMutex);
      } else {
        Serial.println("Falha ao pegar Mutex Log: " + msg);
      }
    }
    String toHtml() {
        String html = "<h3>Logs de Debug (Ultimos 50)</h3>";
        html += "<div style='background: #333; color: #0f0; padding: 10px; border-radius: 5px; font-family: monospace; height: 300px; overflow-y: scroll;'>";
        
        // Iterar do mais antigo para o mais novo
        int start = (count < MAX_LOGS) ? 0 : head;
        for (int i = 0; i < count; i++) {
            int idx = (start + i) % MAX_LOGS;
            html += logs[idx] + "<br>";
        }
        
        html += "</div>";
        html += "<button onclick='location.reload()'>Atualizar</button>";
        html += "<form action='/debug/clear' method='POST' style='display:inline;'><button type='submit'>Limpar</button></form>";
        return html;
    }

    void clear() {
        if (xSemaphoreTake(logMutex, portMAX_DELAY)) {
            head = 0;
            count = 0;
            xSemaphoreGive(logMutex);
        }
    }

    String getLogString() {
        String logStr = "";
        if (xSemaphoreTake(logMutex, portMAX_DELAY)) {
            int start = (count < MAX_LOGS) ? 0 : head;
            for (int i = 0; i < count; i++) {
                int idx = (start + i) % MAX_LOGS;
                logStr += logs[idx] + "\n";
            }
            xSemaphoreGive(logMutex);
        }
        return logStr;
    }
};

DebugLog debugLog;


// ==================== NOVAS CONFIGURAÇÕES DA PLACA ====================
#define BOARD_MODEL "ESP32-S3-HELTEC-WIFI-LORA-32-V3"
#define FW_VERSION 3.0
#define OLED_SDA 17
#define OLED_SCL 18
#define OLED_RST 21
#define OLED_VEXT_POWER 2 // PINO que controla a alimentação do OLED e outros periféricos

// ==================== CONFIGURAÇÕES ====================
#define LED_PIN 35 // LED onboard na Heltec V3 é o pino 35
#define AP_MODE_DURATION 120000

const char* ntpServer = "pool.ntp.org";
const long gmtOffset_sec = -3 * 3600;
const int daylightOffset_sec = 0;

int idSensor = 3;
int distanciaSonda = 0;
int alturaAgua = 200;
String nomeDaSonda = "Torre A Reservatório 01";
String deviceUuid = "";
// Default URLs and Params (Hardcoded defaults as per request)
String novoUrlSite = "https://app.digitalinovation.com.br";
String pingBaseUrl = "https://app.digitalinovation.com.br/ping"; 
String urlVersao = "https://app.digitalinovation.com.br/version.json"; 
int alertLevelCm = 50;
String remoteConfigUrl = "https://app.digitalinovation.com.br/remote.json";



// Deprecated or unused but kept to avoid compilation errors if referenced elsewhere (cleaned up where possible)
String urlSite = "app.digitalinovation.com.br"; 


// ==================== VARIÁVEIS GLOBAIS ====================
long duration;
int distance;
int sensorValue;

// Sensor Smoothing
const int HISTORY_SIZE = 120;
int sensorHistory[HISTORY_SIZE];
int historyIndex = 0;
int historyCount = 0;

// Display - Pinos atualizados para o OLED integrado da Heltec V3
SSD1306Wire display(0x3c, OLED_SDA, OLED_SCL);

// Sonar - Pinos atualizados para melhor conexão na Heltec V3
#define TRIGGER_PIN  19
#define ECHO_PIN1    20
Ultrasonic sonar1(TRIGGER_PIN, ECHO_PIN1, 40000UL);

// Rede
WebServer server(80);
DNSServer dnsServer;
Preferences prefs;
String StatusInternet = "Sem Wifi...";

// Temporizadores
unsigned long lastDisplayUpdate = 0;
const unsigned long displayInterval = 500;
unsigned long lastTime = 0;
unsigned long timerDelay = 60000; // Default 60s
unsigned long bootTime = 0;
bool inAPMode = false;

// LED
unsigned long lastLedToggle = 0;
bool ledState = false;
unsigned long ledInterval = 1000;

// ==================== ESTRUTURAS E PROTÓTIPOS ====================
struct Config {
  String ssid;
  String pass;
  String sensorId;
  String nomeSonda;
};

void setupWiFi();
void switchToAPMode();
void IoT_Task(void *parameter); // Prototipo da Tarefa
void switchToStationMode();
void updateLed();
void handleWiFiEvent(WiFiEvent_t event);
int calculateMode();
void sonar();
void tela();
void IoT();

Config loadConfig();
void saveConfig(String ssid, String pass, String sensorId, String nomeSonda);
void startAccessPoint();
void setupWebServer();
void handleRoot();
void handleSave();
String escapeHTML(String input);
void performUpdate(String url);
void checkForUpdates();
void syncTime();
void setupDeviceID();
void getRemoteConfig();
void sendPing();
void publishSensorReading(int sensorValue);
void handleEsquema();
void handleWiFiScan();
void handleNotFound();
void initRemoteParams();
void saveRemoteParams();
void handleDebug();
void handleDebugClear();
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

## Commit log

2022-02-22 upload de imagens
2022-02-22 upload anel de vedação
2022-02-22 upload fotos
    [Diagrama.fzz, ESP32_Boards.fzz]
2022-03-07 Adicionado códigos para cada Torre
2022-03-09 Corrigido quebra de linha no fim do parametro
2025-06-14 Melhora configuração no AP e muda pinos do sensor
2025-06-14 insere esquema de ligação
2025-06-15 Update esp32_30pin.ino
    Lida com https do github
2025-06-16 Create LILYGO-T-CALL-PMU-AXP192-ESP32.ino
    Prévia
2025-07-20 Create ESP32-C3-042OLED
2025-07-20 Update and rename ESP32-C3-042OLED to ESP32-C3-042OLED.ino
2026-01-31 Multi Thread e com log de debug e moda das leituras
2026-01-31 Corrige para Usar os Dados Salvos em vez dos em memoria
    [ESP32-S3-HELTEC-WIFI-LORA-32-V3.ino]
2026-02-01 Corrige o redirecionamento no ping
    [ESP32-S3-HELTEC-WIFI-LORA-32-V3.ino]
2026-02-01 porta para o ESP-C3
